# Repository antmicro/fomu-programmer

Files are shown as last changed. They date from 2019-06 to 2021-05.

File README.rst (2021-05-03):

===============
Fomu Programmer
===============

Copyright (c) 2019-2021 `Antmicro <https://www.antmicro.com>`_

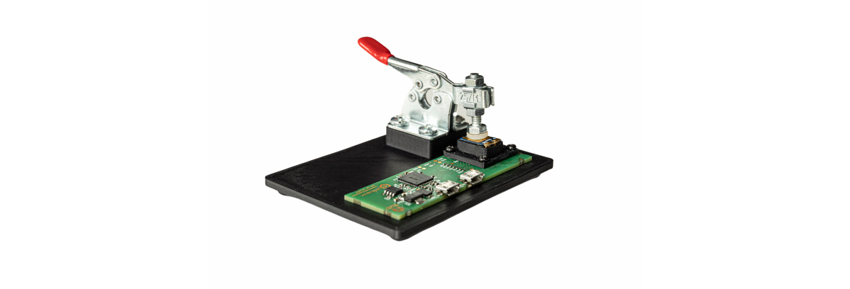
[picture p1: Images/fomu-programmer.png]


Overview
========

This repository contains the open hardware design for `Antmicro's <https://antmicro.com>`_  programming board for Fomu, i.e. the `FPGA incarnation of the Tomu project <https://github.com/im-tomu/fomu-hardware>`_ - an FPGA that fits into your USB port (and the easiesy way to get started with FPGA and/or RISC-V development).
The programmer lets you upload initial firmware into your Fomu over a micro-USB connection.
It is based on a two-channel FT2232 FTDI interface providing JTAG and debug UART interfaces.
Along with PCB design files the repository describes also a Fomu fastening mechanism with a mechanical lever and a PCB fixture which makes Fomu programming more convenient.

Board layout
============

The picture below presents the general layout of the PCB with interface connectors marked.

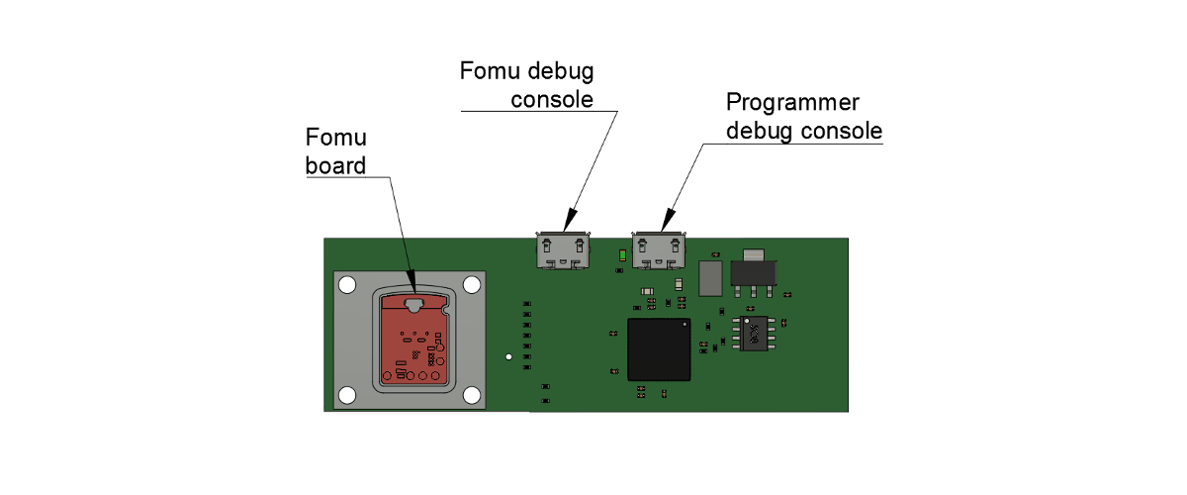
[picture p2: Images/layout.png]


Getting started
===============

The PCB design files define the board layout and recommended stackup for generating the Gerber files.
Please refer to the schematic sheets for more information.
You will need to 3D-print a testbed that will hold your Fomu against the test needles soldered to the PCB.
The programmer enumerates on the host PC as a typical-two channel FTDI device seen under ``/dev/ttyUSB0`` and ``/dev/ttyUSB1`` (assuming no other USB/serial devices are connected)

Please refer to Fomu firmware programming guidelines for further information regarding software setup and flashing.

License
=======

`Apache-2.0 <LICENSE>`_

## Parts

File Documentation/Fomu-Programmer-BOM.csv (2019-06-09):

Manufacturer | PartNumber | Value | Description | Quantity | Designator | Layer
Harwin | P70-2300045R |  | Testpad, round, 1.8mm | 12 | PP1, PP2, PP3, PP4, PP5, PP6, PP9, PP10, PP12, PP14, PP16, PP18 | Top
BOSSARD | M2/BN109 | Nut M2 | Bolt M4x10mm | 4 | M2, M4, M6, M8 | None
Multicomp | R_12k_0402 | 12k | SMT Resistor 0402 | 1 | R11 | Top
Multicomp | R_330R_0402 | 330R | SMT Resistor 0402 | 1 | R17 | Top
KINGBRIGHT | LED_G | KPT-1608SGC | LED Green 0603 case | 1 | LED1 | Top
BOSSARD | M4/BN1052 | Insert M4 | Bolt M4x10mm | 4 | M10, M12, M14, M16 | None
ELESA+GANTER | GN 820-25-M | GN 820-25-M |  | 1 | COMP1 | None
FTDI | FT2232HQ | FT2232HQ | Dual USB-UART/FIFO | 1 | IC2 | Top
Vishay | R_0R_0402 | 0R | SMT Resistor 0402 | 10 | R1, R2, R3, R4, R5, R6, R7, R9, R10, R15 | Top
Vishay | R_10k_0402 | 10k | SMT Resistor 0402 | 3 | R12, R13, R14 | Top
Vishay | R_2k2_0402 | 2k2 | SMT Resistor 0402 | 2 | R8, R16 | Top
TDK | C_4u7_0402 | 4u7 | MLCC SMT Capacitor 100nF 0402 | 4 | C2, C8, C12, C13 | Top
BOSSARD | M4X10/BN1435 SN213306 | Bolt M4x10mm | Bolt M4x10mm | 4 | M9, M11, M13, M15 | None
BOSSARD | M2X10/BN1435 | Bolt M2x10mm | Bolt M4x10mm | 4 | M1, M3, M5, M7 | None
MURATA | BLM18AG601SN1D | BLM18AG601SN1D | Ferrite Bead, 600 ohm, 0603 [1608 Metric], BLM18A Series, 500 mA, 0.38 ohm, ? 25% | 2 | L1, L2 | Top
Abracon LLC | ASFLMB-12.000MHZ-LC-T | ASFLMB-12.000MHZ-LC-T | MEMS Oscillator, Ultra-miniature, 12 MHz, SMD, 5mm x 3.2mm, 50 ppm, 3.3 V | 1 | IC4 | Top
DIODES INC. | AP1117E33G-13 | AP1117E33G-13 | IC, LDO, REG, 3.3V, SOT223 | 1 | IC3 | Top
Molex | CON-Molex-47346-0001 | Molex 47346-0001 | USB - micro B Receptacle Connector 5 Position Surface Mount, Right Angle, Horizontal | 2 | J1, J2 | Top
AVX | C_100n_0402 | 100n | MLCC SMT Capacitor 100nF 0402 | 10 | C1, C3, C4, C5, C6, C7, C9, C10, C11, C14 | Top
Microchip Technology | 93LC56C | 93LC56C-I/SN-ND | EEPROM SERIAL 1K, SMD, 93C46, SOIC8 | 1 | IC1 | Top

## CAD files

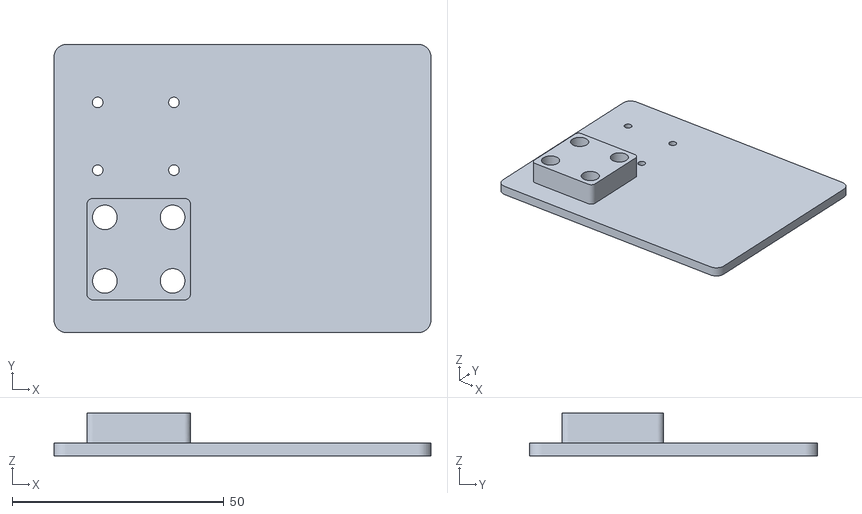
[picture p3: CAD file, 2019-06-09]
3Dmodels/fomu-programming-table.stl
89.0 x 68.0 x 10.1

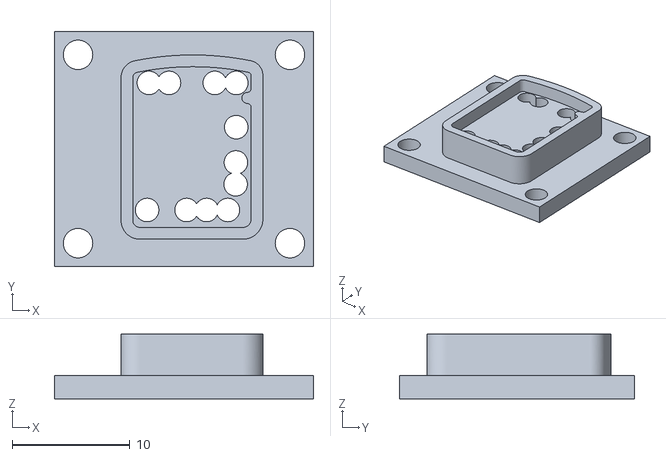
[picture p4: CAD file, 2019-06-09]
3Dmodels/fomu-testbed.stl
22.0 x 20.0 x 5.50

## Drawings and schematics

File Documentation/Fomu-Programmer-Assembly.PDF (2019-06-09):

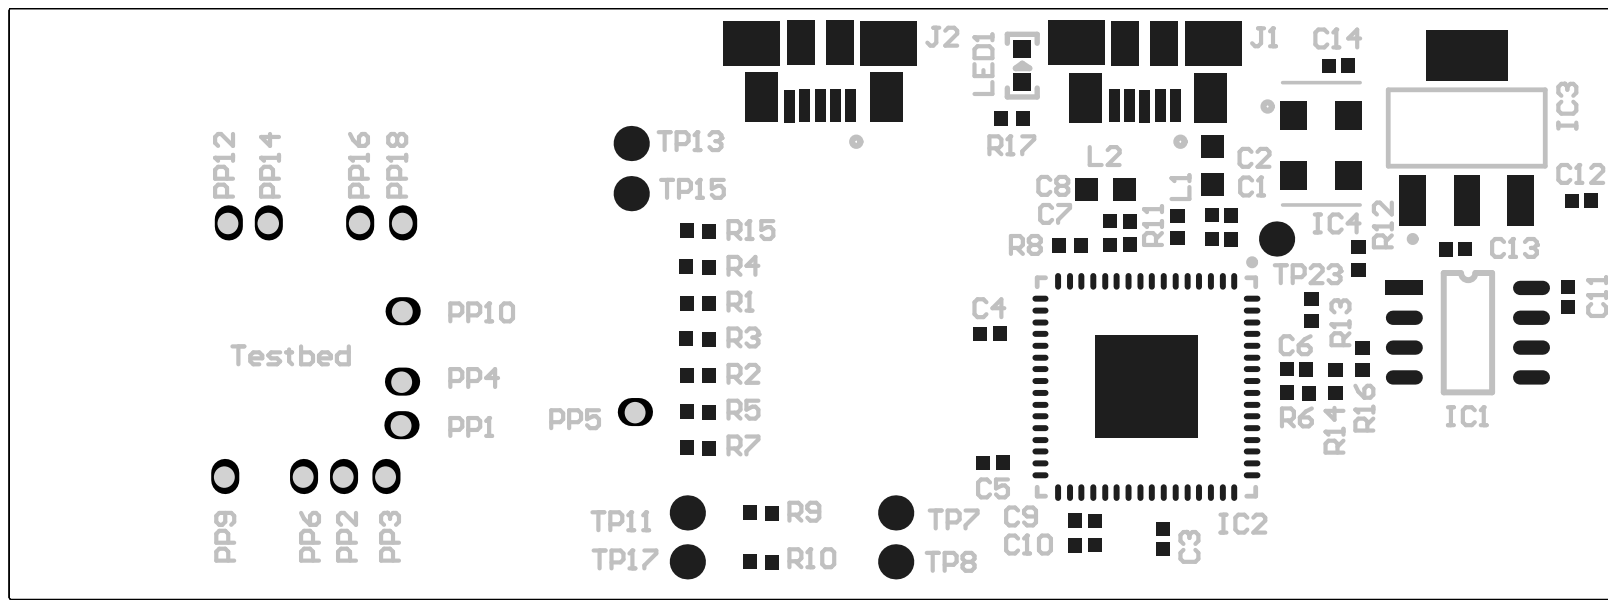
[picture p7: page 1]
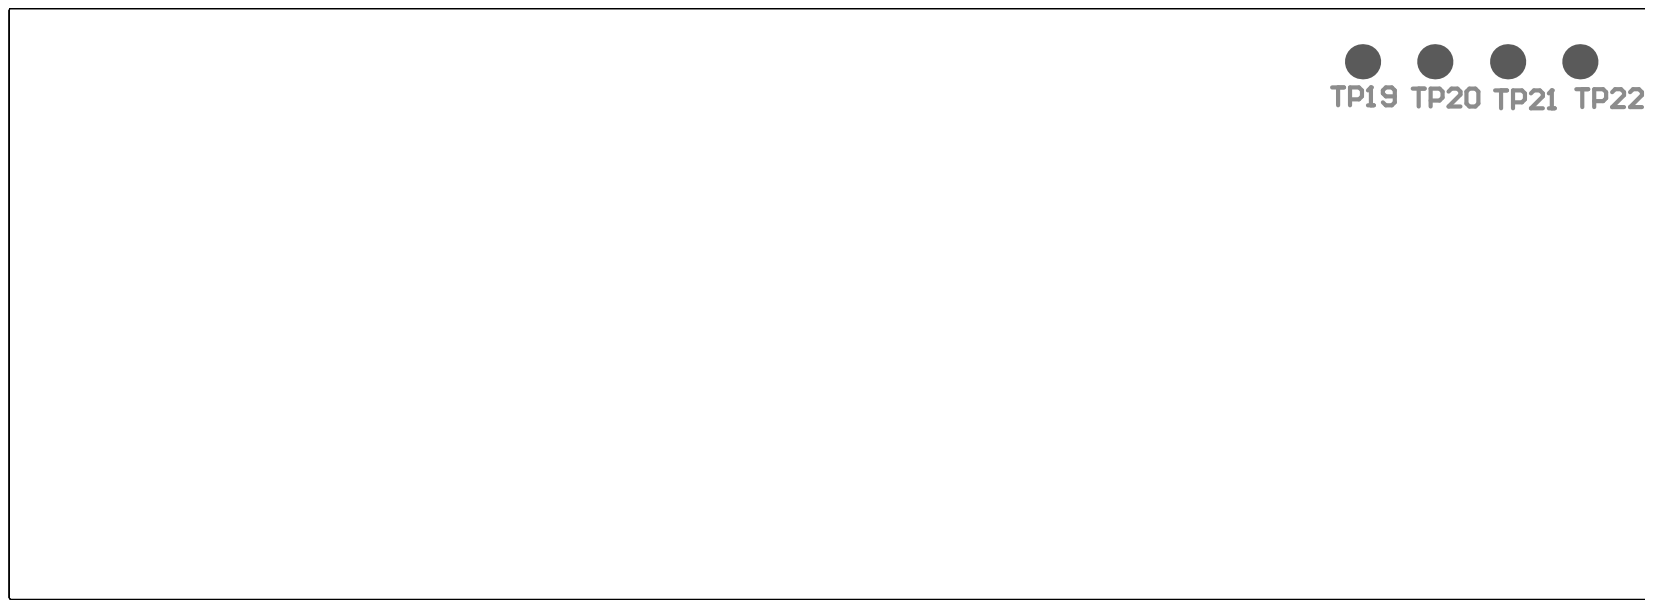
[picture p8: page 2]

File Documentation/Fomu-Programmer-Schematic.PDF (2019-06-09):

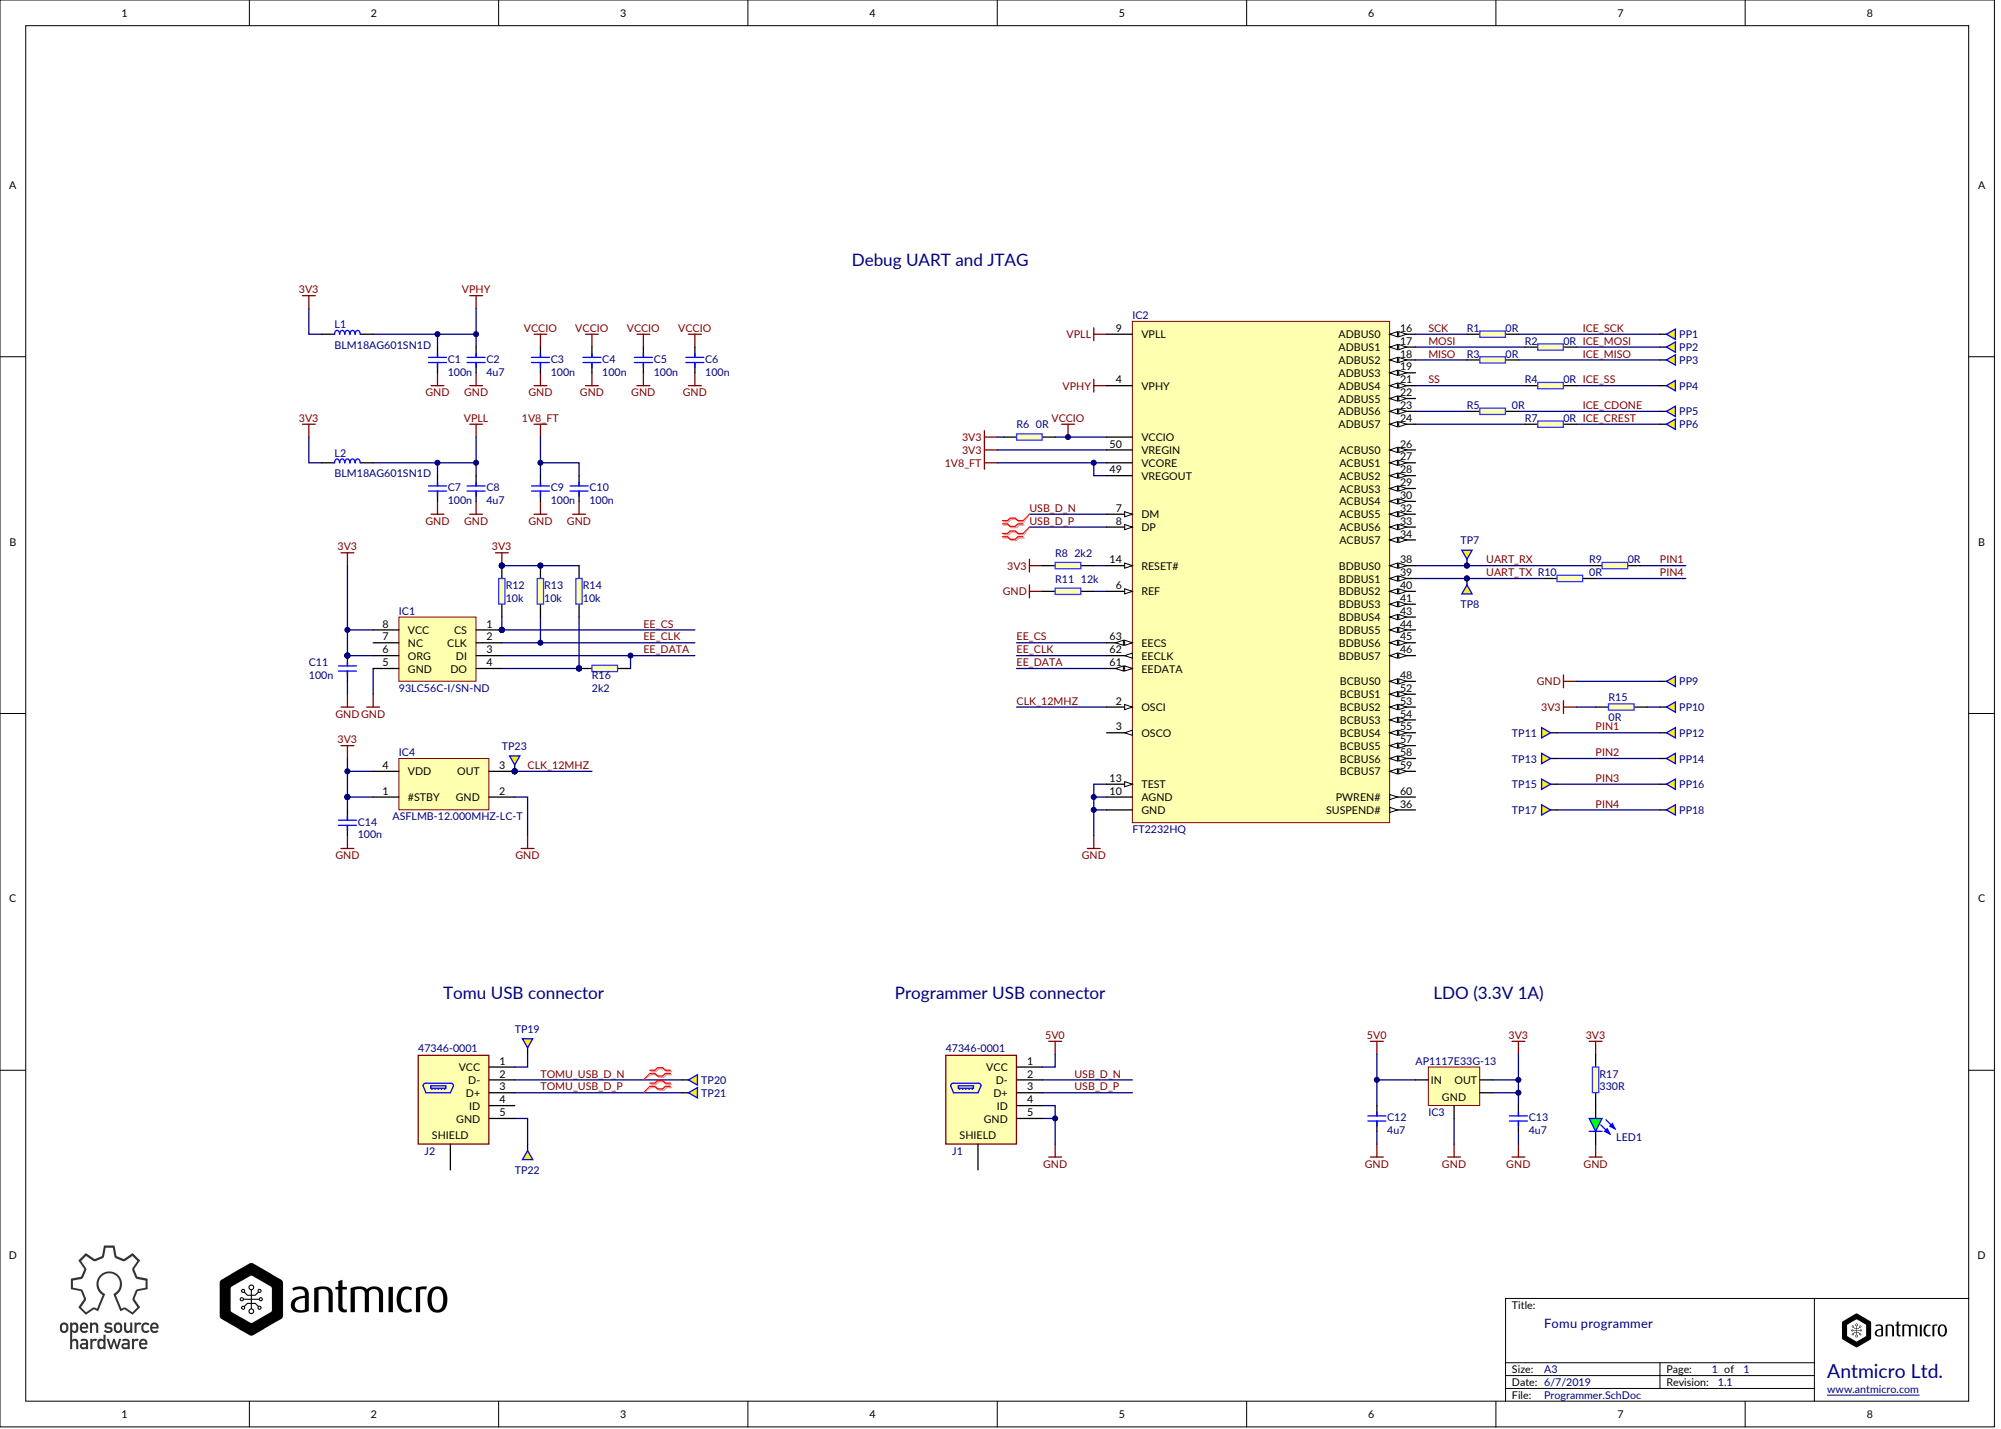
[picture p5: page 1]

Debug UART and JTAG

Title: F o m u p r o g r a m m e r | Antmicro Ltd. www.antmicro.com

Size: A3 | Page: 1 of 1
Date: 6/7/2019 | Revision: 1.1

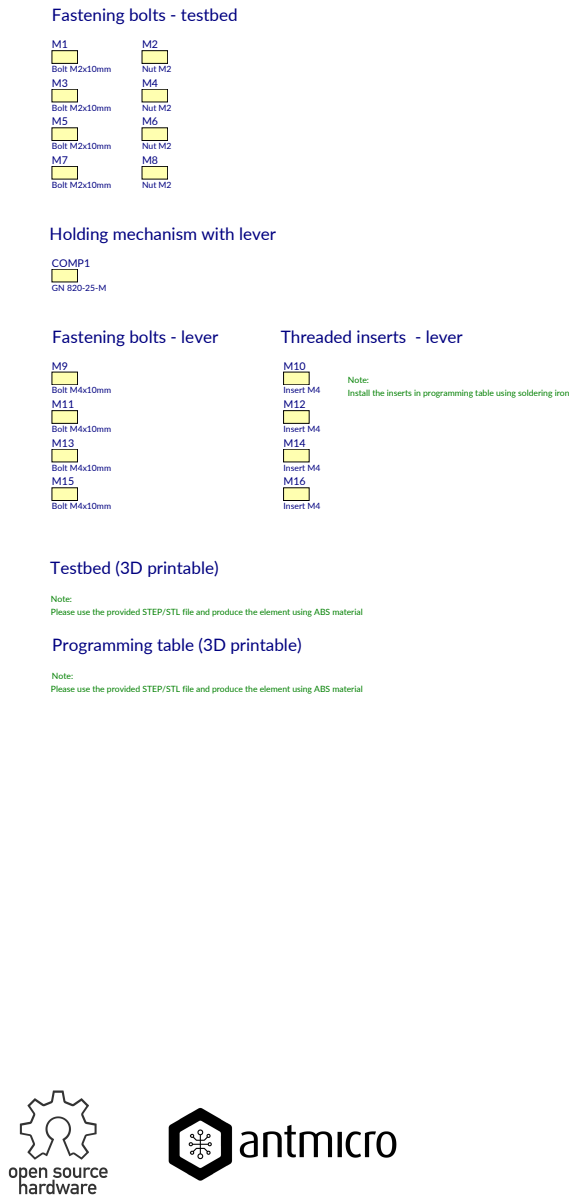
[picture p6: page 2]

Holding mechanism with lever

Note:
Install the inserts in programming table using soldering iron

Please use the provided STEP/STL file and produce the element using ABS material
Programming table (3D printable)

Title: Fomu programmer | Antmicro Ltd. www.antmicro.com

Size: A3 | Page: 1 of 2
Date: 6/7/2019 | Revision: 1.1
